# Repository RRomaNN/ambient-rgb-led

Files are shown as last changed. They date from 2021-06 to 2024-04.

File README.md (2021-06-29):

# Ambient backlight with addressable RGB strip [WIP]

This is a **prototype** of the LED backlight controller.

in short:

you can upload an image (ie pattern) from the computer to the device. The pattern will be read row by row by the controller and rows will be sequentially displayed on the addressable LED strip using the selected color schema with preselected speed and smooth color transitions between the rows.

Features:

- Supports up to 16 patterns, stored in 4x AT24C256 EEPROMs. You can interactively select one of them at a time.
- Supports up to 32 custom color schemas. You can create/edit/save them to EEPROM directly on the device using buttons, LCD and the short *preview* led strip.
- Supports different pattern playback speeds. From ~3 smooth transitions/second to 1 transition per 2 minutes. You can select the one you need.
- Measures amperage of the LED strip and displays it on the LCD in the operating mode. 
- TODO: Add feature, which allows limiting max current draw by LED strip to prevent damage of DC power supply / PCB.

- Load current - up to 10A.
- Distance between the controller and LED strip - up to 5 meters (the device contains repeater of the output digital signal)
- Protection from the minor static discharges over +5V, DOUT, GND lines (no TVS diodes though)

Schema:

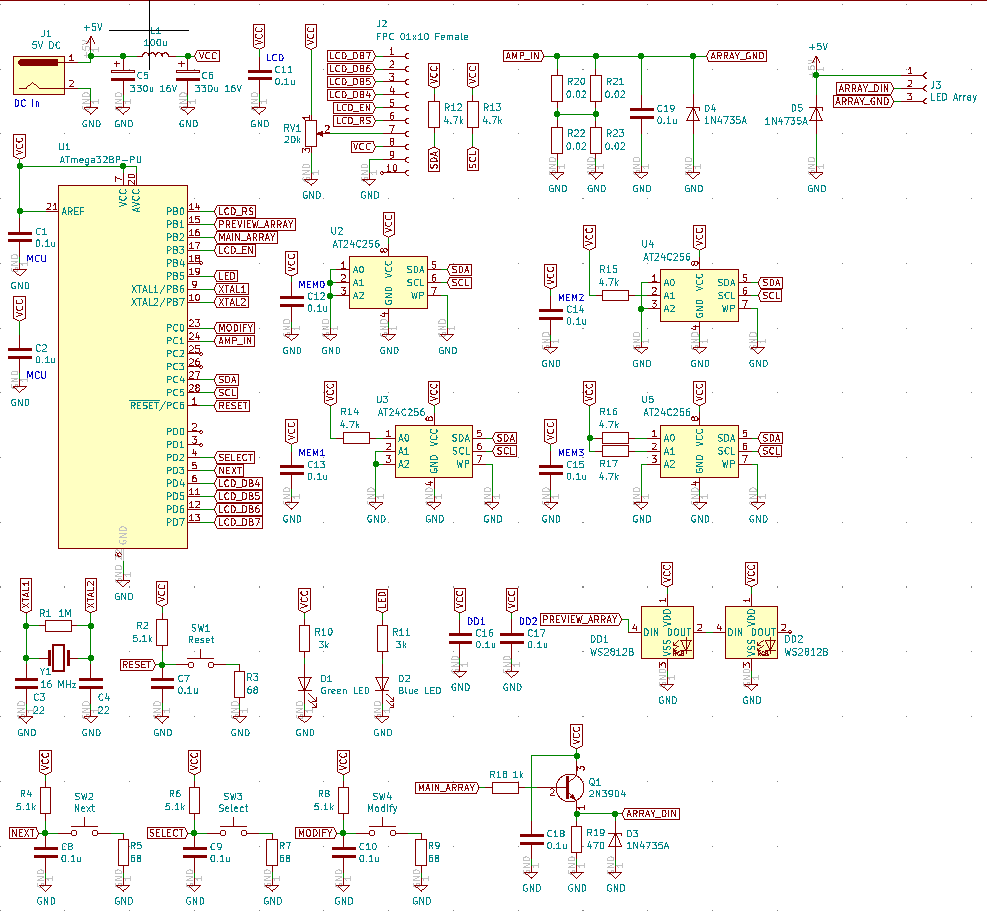
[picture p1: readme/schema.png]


PCB front view:

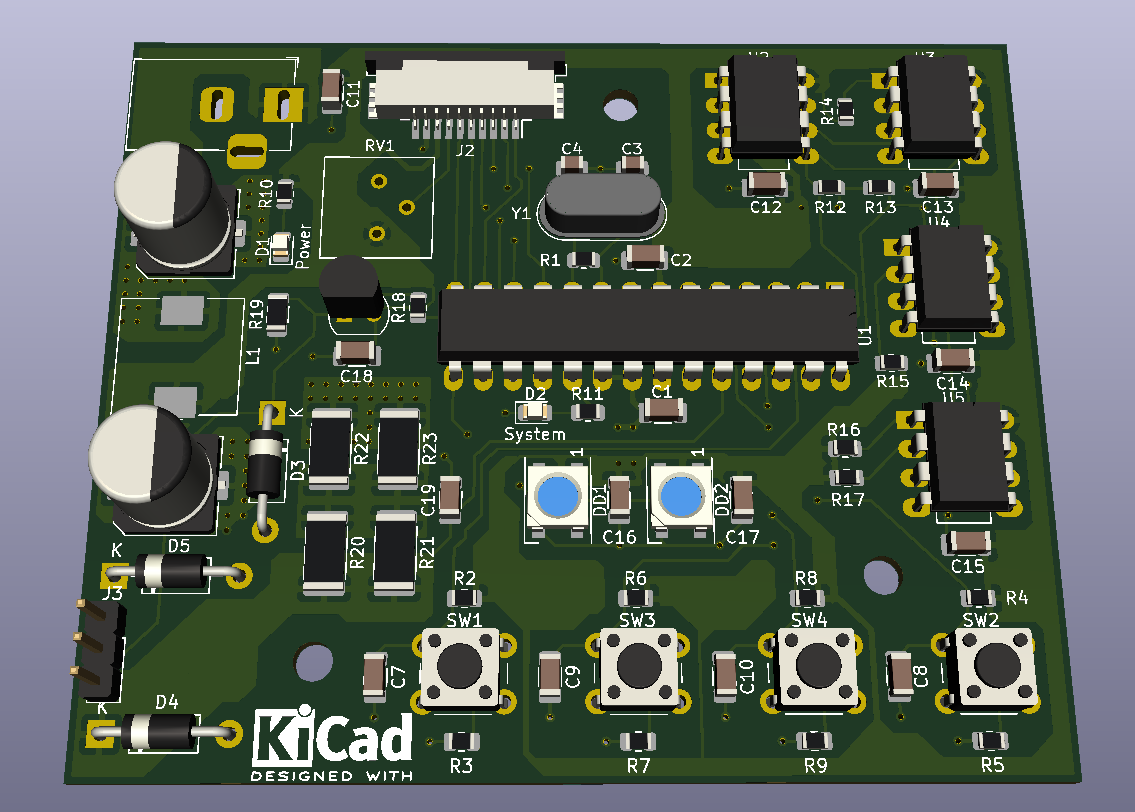
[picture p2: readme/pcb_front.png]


PCB back view:

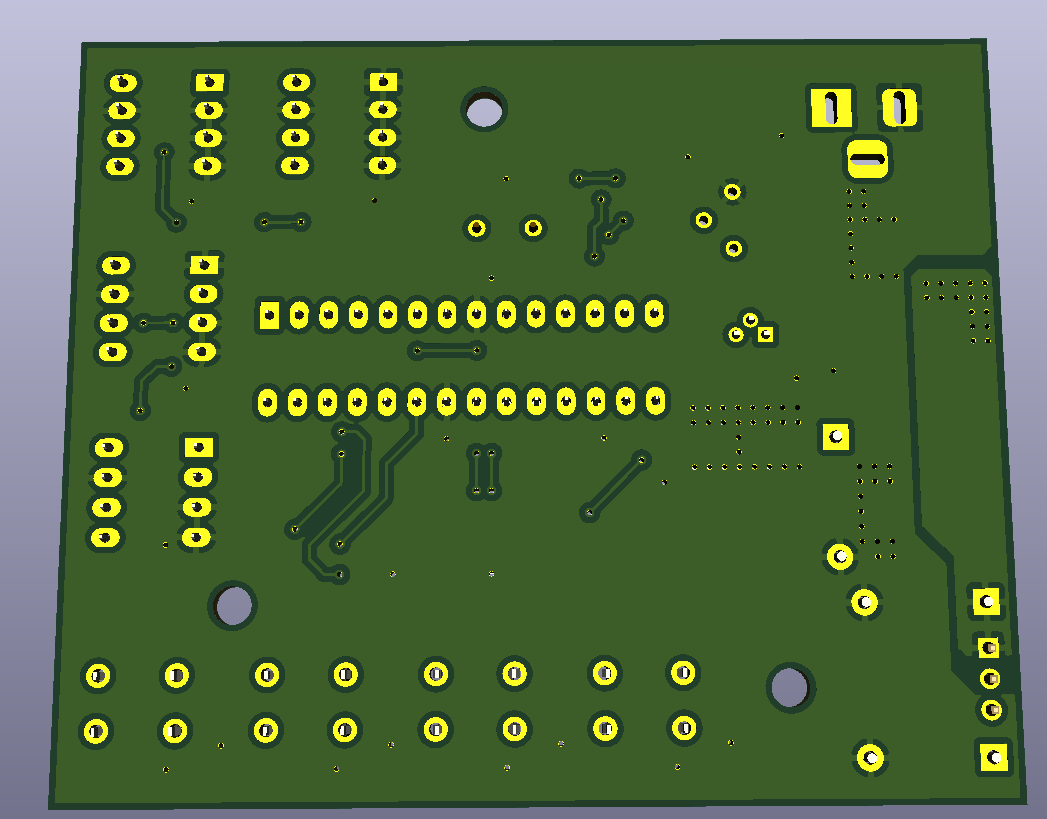
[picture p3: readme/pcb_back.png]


Firmware:

[controller.ino](https://github.com/RRomaNN/ambient-rgb-led/blob/main/controller_c/controller.ino)

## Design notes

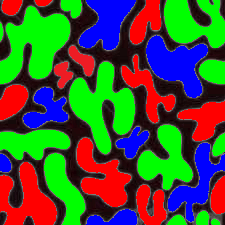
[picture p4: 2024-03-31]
image_converter_cs/BitConverter/4-color-image.bmp

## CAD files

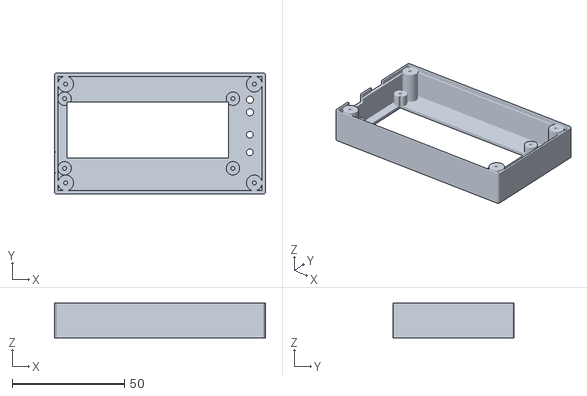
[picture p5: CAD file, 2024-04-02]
free-cad—cpy/front_v2.stl
94.0 x 54.0 x 15.6

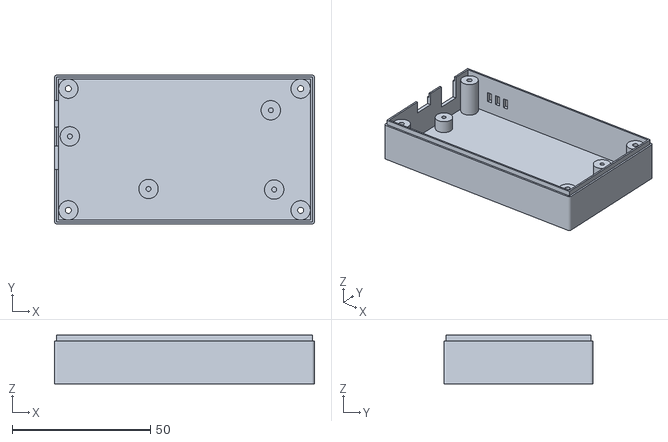
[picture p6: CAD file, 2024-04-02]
free-cad—cpy/back_v2.stl
94.0 x 54.0 x 17.5

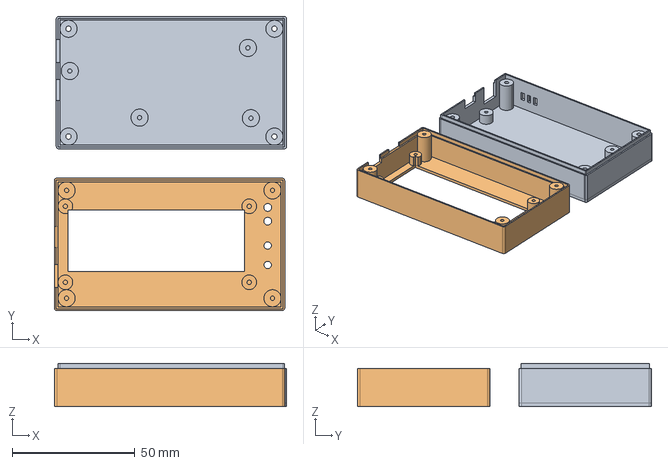
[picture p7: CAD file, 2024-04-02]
free-cad—cpy/case-bottom.FCStd
94.8 x 119.9 x 17.6 mm

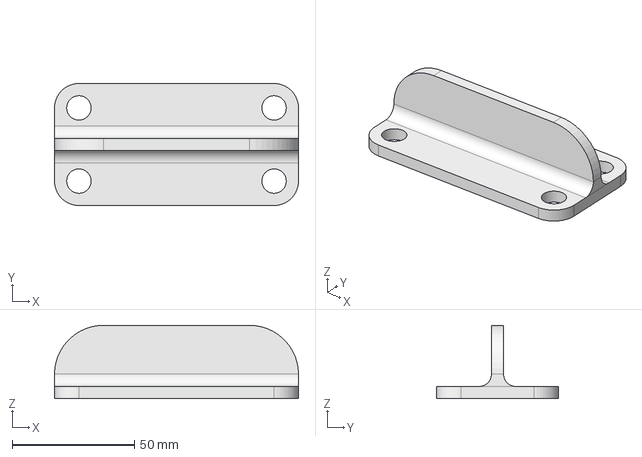
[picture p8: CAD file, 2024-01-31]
free-cad—cpy/test2.FCStd
100.0 x 50.0 x 30.0 mm

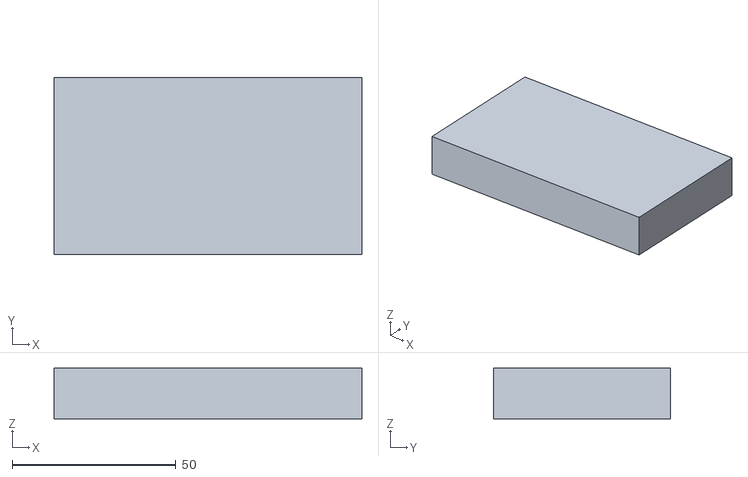
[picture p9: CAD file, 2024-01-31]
free-cad—cpy/case-bottom-Body001Pad009.stl
94.0 x 54.0 x 15.6

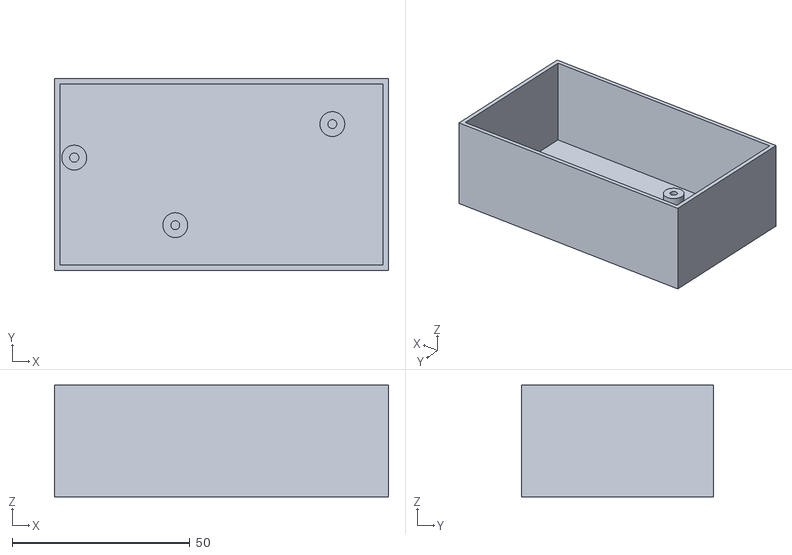
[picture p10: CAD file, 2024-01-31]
free-cad—cpy/case-bottom-BodyPocket002.stl
94.0 x 54.0 x 31.5

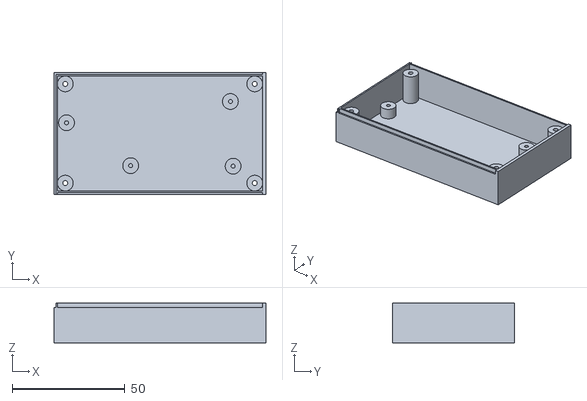
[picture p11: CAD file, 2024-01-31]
free-cad—cpy/case-bottom-BodyPocket010.stl
94.0 x 54.0 x 17.5

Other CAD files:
free-cad—cpy/test.FCStd
free-cad—cpy/test2-BodyFillet002.stl
free-cad—cpy/back.stl
free-cad—cpy/front.stl

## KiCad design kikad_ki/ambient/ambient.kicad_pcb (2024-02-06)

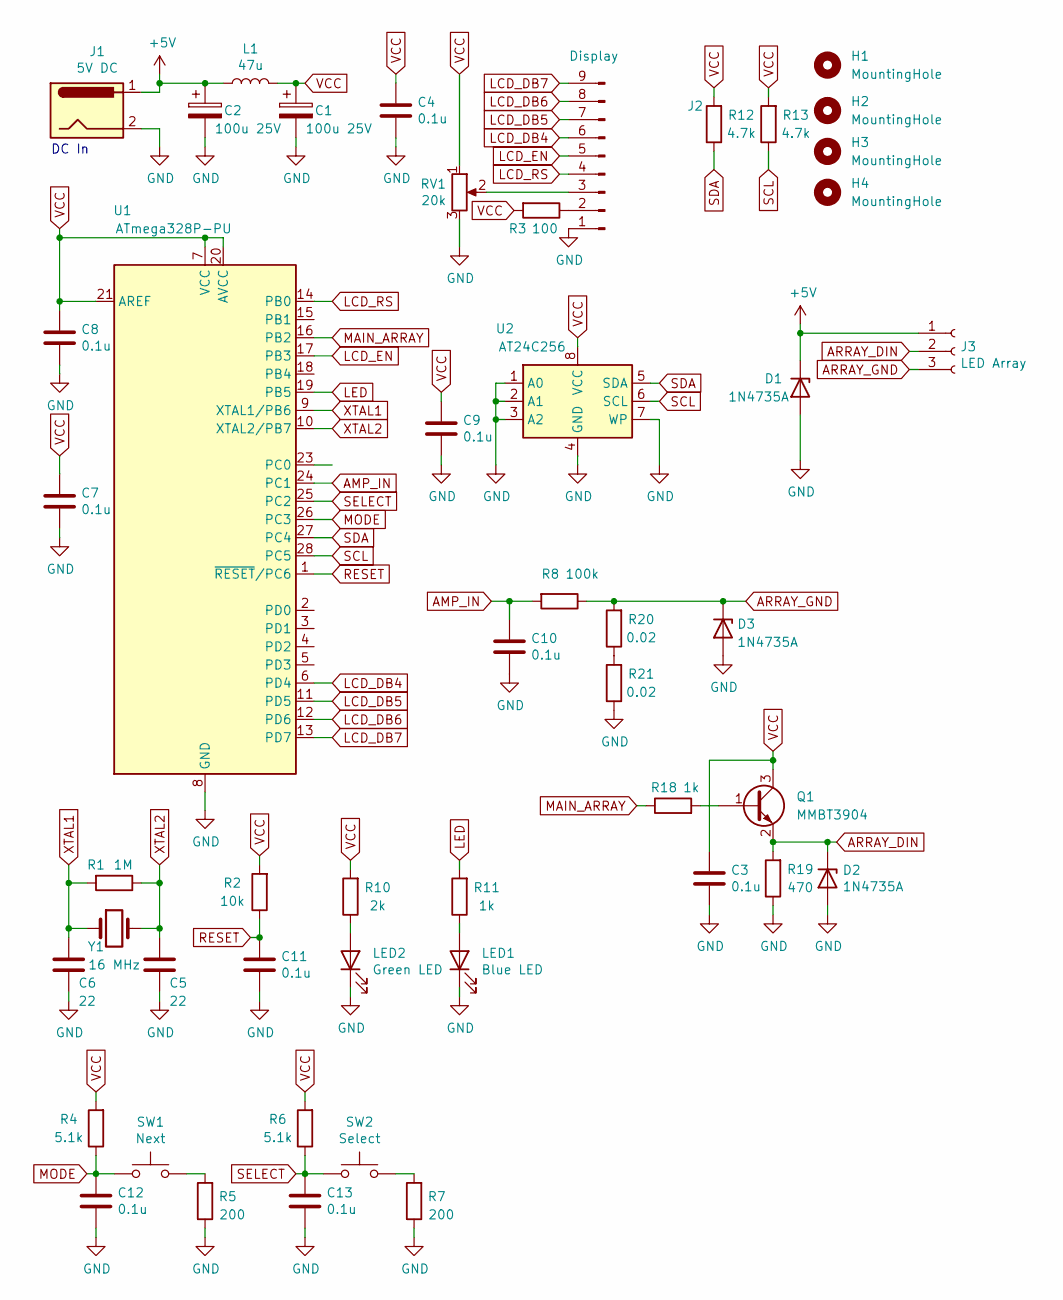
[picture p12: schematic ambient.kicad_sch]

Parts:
C1, C2: 100u 25V; CP_Elec_8x10
C3, C4, C7, C8, C9, C10, C11, C12, C13: 0.1u; C_0805_2012Metric
C5, C6: 22; C_0805_2012Metric
D1, D2, D3: 1N4735A; D_MiniMELF
H1, H2, H3, H4: MountingHole; MountingHole_3.2mm_M3_DIN965_Pad
J1: 5V DC; BarrelJack_Horizontal
J2: Display; PinHeader_1x09_P2.54mm_Vertical
J3: LED Array; PinHeader_1x03_P2.54mm_Vertical
L1: 47u; L_10.4x10.4_H4.8
LED1: Blue LED; LED_D3.0mm_Clear
LED2: Green LED; LED_D3.0mm_Clear
Q1: MMBT3904; SOT-23
R1: 1M; R_0805_2012Metric
R2: 10k; R_0805_2012Metric
R3: 100; R_1206_3216Metric
R4, R6: 5.1k; R_0805_2012Metric
R5, R7: 200; R_0805_2012Metric
R8: 100k; R_0805_2012Metric
R10: 2k; R_0805_2012Metric
R11, R18: 1k; R_0805_2012Metric
R12, R13: 4.7k; R_0805_2012Metric
R19: 470; R_1206_3216Metric
R20, R21: 0.02; R_2512_6332Metric
RV1: 20k; Potentiometer_Bourns_3386P_Vertical
SW1: Next; SW_PUSH_6mm
SW2: Select; SW_PUSH_6mm
U1: ATmega328P-PU; DIP-28_W7.62mm_LongPads
U2: AT24C256; DIP-8_W7.62mm_LongPads
Y1: 16 MHz; Crystal_HC49-4H_Vertical

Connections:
+5V: C2.1, D1.1 (K), J1.1, J3.1, L1.1
AMP_IN: C10.1, R8.2, U1.24 (PC1)
ARRAY_DIN: D2.1 (K), J3.2, Q1.2 (E), R19.2
ARRAY_GND: D3.1 (K), J3.3, R8.1, R20.2
GND: C1.2, C2.2, C3.2, C4.2, C5.2, C6.2, C7.2, C8.2, C9.2, C10.2, C11.2, C12.2, C13.2, D1.2 (A), D2.2 (A), D3.2 (A), J1.2, J2.1, LED1.1 (K), LED2.1 (K), R5.1, R7.1, R19.1, R21.1, RV1.3, U1.8 (GND), U1.22 (GND), U2.1 (A0), U2.2 (A1), U2.3 (A2), U2.4 (GND), U2.7 (WP)
LCD_DB4: J2.6, U1.6 (PD4)
LCD_DB5: J2.7, U1.11 (PD5)
LCD_DB6: J2.8, U1.12 (PD6)
LCD_DB7: J2.9, U1.13 (PD7)
LCD_EN: J2.5, U1.17 (PB3)
LCD_RS: J2.4, U1.14 (PB0)
LED: R11.2, U1.19 (PB5)
MAIN_ARRAY: R18.1, U1.16 (PB2)
MODE: C12.1, R4.1, SW1.1, U1.26 (PC3)
unnamed: J2.2, R3.1
unnamed: J2.3, RV1.2
unnamed: LED1.2 (A), R11.1
unnamed: LED2.2 (A), R10.1
unnamed: Q1.1 (B), R18.2
unnamed: R5.2, SW1.2
unnamed: R7.2, SW2.2
unnamed: R20.1, R21.2
RESET: C11.1, R2.1, U1.1 (~RESET/PC6)
SCL: R13.1, U1.28 (PC5), U2.6 (SCL)
SDA: R12.1, U1.27 (PC4), U2.5 (SDA)
SELECT: C13.1, R6.1, SW2.1, U1.25 (PC2)
VCC: C1.1, C3.1, C4.1, C7.1, C8.1, C9.1, L1.2, Q1.3 (C), R2.2, R3.2, R4.2, R6.2, R10.2, R12.2, R13.2, RV1.1, U1.7 (VCC), U1.20 (AVCC), U1.21 (AREF), U2.8 (VCC)
XTAL1: C6.1, R1.2, U1.9 (XTAL1/PB6), Y1.1
XTAL2: C5.1, R1.1, U1.10 (XTAL2/PB7), Y1.2

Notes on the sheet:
DC In

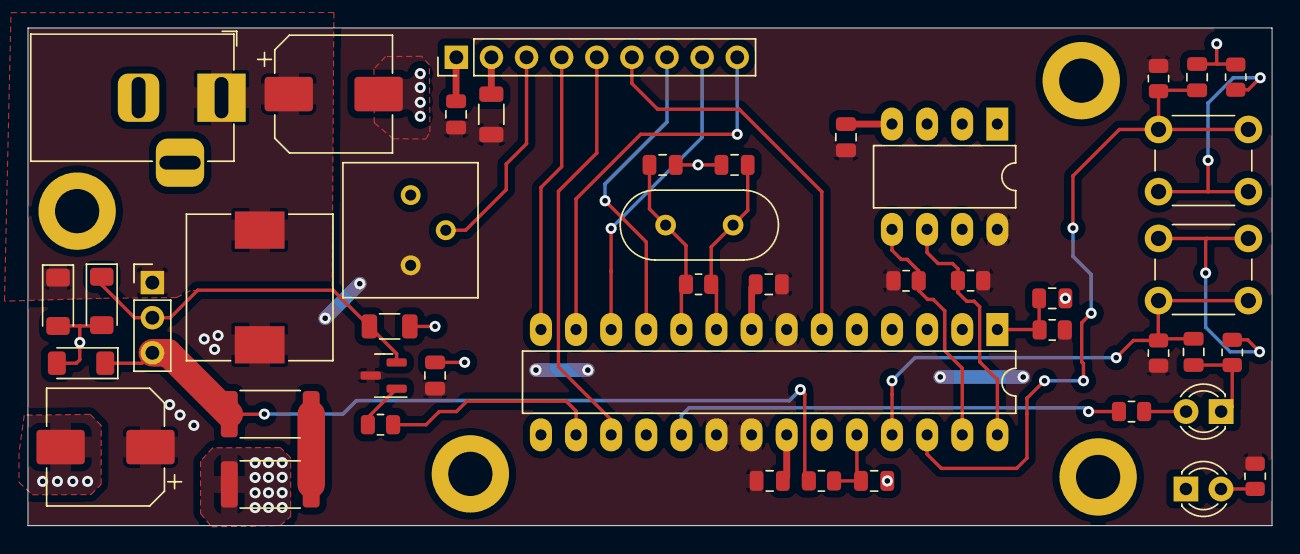
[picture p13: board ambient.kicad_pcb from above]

Board: 2 copper layers, 90.0 x 36.0 mm, 49 parts (0 on the bottom side), 29 nets.

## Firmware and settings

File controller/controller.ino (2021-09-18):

#include <Wire.h>
#include <LiquidCrystal.h>
#include <Adafruit_NeoPixel.h>

#define IRQ0 2
#define IRQ1 3

#define LCD_RS 8
#define LCD_EN 11
#define LCD_D4 4
#define LCD_D5 5
#define LCD_D6 6
#define LCD_D7 7

#define LED_PREVIEW_ARRAY_PIN 9
#define LED_MAIN_ARRAY_PIN 10

#define LED_PREVIEW_ARRAY_PIXEL_NUM 2
#define LED_MAIN_ARRAY_PIXEL_NUM 183

#define LED_ARRAY_BRIGHTNESS 240 // Not 255

#define EEPROM_BASE_ADDRESS 0x50

#define MAX_IMG_LEN 225
#define ARRAY_PATTERN_LEN 32

#define PATTERN_MAX_COUNT_PER_EEPROM 4
#define PATTERN_MAX_INDEX 3 // Pattern count - 1
#define MAX_PREDEFINED_COLORS 32

#define MODIFY_BUTTON_PIN A0
#define AMPERE_METER_PIN A1

#define AMPERE_METER_AVG_BUFF_SIZE 20
#define ADC_VOLT_TO_AMP_COEF 0.2443
#define MAX_LED_ARRAY_CURRENT 8.0

LiquidCrystal lcd(LCD_RS, LCD_EN, LCD_D4, LCD_D5, LCD_D6, LCD_D7);

Adafruit_NeoPixel preview_led_array(LED_PREVIEW_ARRAY_PIXEL_NUM, LED_PREVIEW_ARRAY_PIN, NEO_GRBW + NEO_KHZ800);
Adafruit_NeoPixel led_array(LED_MAIN_ARRAY_PIXEL_NUM, LED_MAIN_ARRAY_PIN, NEO_GRBW + NEO_KHZ800);

enum stateType {patternSelect, colorSelect, editMainRColor, editMainGColor, editMainBColor, editSecondaryRColor, editSecondaryGColor, editSecondaryBColor, speedSelect, validate, pause, resumeBack};
enum buttonType {selectButton, actionButton, modifyButton};

volatile enum stateType state = patternSelect; 

volatile int pattern_index = 0;
volatile int pattern_preview_line_offset = 0;

volatile char schema_name[12] = "N/A";

volatile char pattern_preview_line0[21];
volatile char pattern_preview_line1[21];
volatile char pattern_preview_line2[21];

volatile bool isSelectPressed = false;
volatile bool isActionPressed = false;

volatile byte main_red = 0xFF;
volatile byte main_green = 0xFF;
volatile byte main_blue = 0xFF;
volatile char main_color_hex[7];

volatile byte secondary_red = 0x00;
volatile byte secondary_green = 0x00;
volatile byte secondary_blue = 0x00;
volatile char secondary_color_hex[7];

volatile bool color_preview = false;
volatile int color_modify_reading_count = 0;
volatile int color_up_momentum = 0;
volatile int color_down_momentum = 0;
volatile byte color_index = 0;

volatile byte pattern_line_offset = 0;
volatile byte pattern_line_interval = 30;
volatile int pattern_count = 0;
volatile byte current_line_data[ARRAY_PATTERN_LEN];
volatile byte next_line_data[ARRAY_PATTERN_LEN];

volatile int currents[AMPERE_METER_AVG_BUFF_SIZE];
volatile byte currents_index = 0;

volatile byte ledArrayBrightness;

void setup() 
{  
  pinMode(LED_BUILTIN, OUTPUT);

  hello();
  
  cli();
 
  pinMode(IRQ0, INPUT);
  pinMode(IRQ1, INPUT);
 
  attachInterrupt(0, selectInterrupt, FALLING);    
  attachInterrupt(1, actionInterrupt, FALLING);  

  sei();

  Wire.begin();
  
  lcd.begin(20, 4);
  lcd.clear();

  preview_led_array.begin();
  preview_led_array.setBrightness(LED_ARRAY_BRIGHTNESS);

  ledArrayBrightness = LED_ARRAY_BRIGHTNESS;
  led_array.begin();
  led_array.setBrightness(ledArrayBrightness);

  readCurrentSchemaName(pattern_index);
  readCurrentPatternPreview(pattern_index, pattern_preview_line_offset);
  
  cancelPreviewColors();
  turnOffLedArray();

  readCurrentState();
  state = pause;
}

void hello()
{
  digitalWrite(LED_BUILTIN, HIGH);
  delay(100);
  digitalWrite(LED_BUILTIN, LOW);
  delay(100);
  digitalWrite(LED_BUILTIN, HIGH);
  delay(100);
  digitalWrite(LED_BUILTIN, LOW);
  delay(100);
  digitalWrite(LED_BUILTIN, HIGH);
  delay(100);
  digitalWrite(LED_BUILTIN, LOW);
}

void loop() 
{
  if(isSelectPressed)
  {
    transitState(selectButton);
    isSelectPressed = false;
  }

  if(isActionPressed)
  {
    transitState(actionButton);
    isActionPressed = false;
  }

  processModifyButton();
  if(color_modify_reading_count == 10)
  {
    color_modify_reading_count = 0;
    transitState(modifyButton);
  }

  render();

  if(state == patternSelect)
    preview();

  if((state == patternSelect || state == speedSelect || state == validate || state == pause || state == resumeBack) && color_preview)
  {
    color_preview = false;
    cancelPreviewColors();
  }    

  if(state == pause)
  {
    digitalWrite(LED_BUILTIN, HIGH);
    renderLedArray();
  }

  delay(100);
}

void renderLedArray()
{
  if(pattern_count == pattern_line_interval)
  {  
    pattern_count = 0;   
    
    //update pattern
    pattern_line_offset = pattern_line_offset == MAX_IMG_LEN - 1 ? 0 : pattern_line_offset + 1;

    byte eeprom_address = getEepromAddress(pattern_index);
    int patternBaseAddress = getAddressOffset(pattern_index);
    
    int patternAddress = patternBaseAddress + ARRAY_PATTERN_LEN * (1 + pattern_line_offset); //32 (256/8) * (225 + 1 for header) + header row;
    for(int i = 0; i < ARRAY_PATTERN_LEN; i++)
      current_line_data[i] = readEEPROM(eeprom_address, patternAddress + i);
      
    int nextPatternOffset = pattern_line_offset == MAX_IMG_LEN - 1 ? 0 : pattern_line_offset + 1;
    
    patternAddress = patternBaseAddress + ARRAY_PATTERN_LEN * (1 + nextPatternOffset);
    for(int i = 0; i < ARRAY_PATTERN_LEN; i++)
      next_line_data[i] = readEEPROM(eeprom_address, patternAddress + i);
  }
  else
    pattern_count++;

  setLedArrayColors();
  saveCurrentState();
}

void setLedArrayColors()
{
  float newFraction = (float)pattern_count / pattern_line_interval;
  float oldFraction = 1 - newFraction;
  
  for(byte i = 0; i < LED_MAIN_ARRAY_PIXEL_NUM; i++)
  {
    bool currentValue = current_line_data[i / 8] & (1 << i % 8);
    bool nextValue = next_line_data[i / 8] & (1 << i % 8);

    byte red, green, blue, white;
    if(currentValue && nextValue)
    {
      white = getWhite(main_red, main_green, main_blue);
      led_array.setPixelColor(i, led_array.Color(main_red - white, main_green - white, main_blue - white, white));  
      continue;
    }

    if(!currentValue && !nextValue)
    {
      white = getWhite(secondary_red, secondary_green, secondary_blue);
      led_array.setPixelColor(i, led_array.Color(secondary_red - white, secondary_green - white, secondary_blue - white, white));  
      continue;
    }

    if(currentValue && !nextValue)
    {
      red = main_red * oldFraction + secondary_red * newFraction;
      green = main_green * oldFraction + secondary_green * newFraction;
      blue = main_blue * oldFraction + secondary_blue * newFraction; 
    }
    else
    {
      red = main_red * newFraction + secondary_red * oldFraction;
      green = main_green * newFraction + secondary_green * oldFraction;
      blue = main_blue * newFraction + secondary_blue * oldFraction; 
    }
    white = getWhite(red, green, blue);
    led_array.setPixelColor(i, led_array.Color(red - white, green - white, blue - white, white)); 
  }
  led_array.show();
}

byte getWhite(byte red, byte green, byte blue)
{
  byte rb = red < green ? red : green;
  return rb < blue ? rb : blue;
}


void processModifyButton()
{
  int modify_button_reading = analogRead(MODIFY_BUTTON_PIN);
  if(modify_button_reading < 256)
    color_modify_reading_count++;
  else
    color_modify_reading_count = 0;
}

void preview()
{
  pattern_preview_line_offset = pattern_preview_line_offset == MAX_IMG_LEN - 1 ? 0 : pattern_preview_line_offset + 1;
  readCurrentPatternPreview(pattern_index, pattern_preview_line_offset);
}

void selectInterrupt()
{
  if(!isSelectPressed)
    isSelectPressed = true;
}

void actionInterrupt()
{
  if(!isActionPressed)
    isActionPressed = true;
}

void transitState(enum buttonType button)
{
  switch(state)
  {
    case patternSelect:
      switch(button)
      {
        case selectButton:
          pattern_index = pattern_index == PATTERN_MAX_INDEX ? 0 : pattern_index + 1;
          readCurrentSchemaName(pattern_index);    
          readCurrentPatternPreview(pattern_index, pattern_preview_line_offset);
          break;
        case actionButton:
          state = colorSelect;
          readColors();
          break;
      }
      break;
    case colorSelect:
      switch(button)
      {
        case selectButton:
          color_index = color_index == MAX_PREDEFINED_COLORS - 1 ? 0 : color_index + 1;
          readColors();
          break;
        case actionButton:
          state = speedSelect;
          break;
        case modifyButton:
          state = editMainRColor;
          break;
      }
      break;
    case editMainRColor:
      switch(button)
      {
        case selectButton:
          main_red = colorDown(main_red);
          break;
        case actionButton:
          main_red = colorUp(main_red);
          break;
        case modifyButton:
          state = editMainGColor;
          break;
      }
      break;
    case editMainGColor:
      switch(button)
      {
        case selectButton:
          main_green = colorDown(main_green);
          break;
        case actionButton:
          main_green = colorUp(main_green);
          break;
        case modifyButton:
          state = editMainBColor;
          break;
      }
      break;
    case editMainBColor:
      switch(button)
      {
        case selectButton:
          main_blue = colorDown(main_blue);
          break;
        case actionButton:
          main_blue = colorUp(main_blue);
          break;
        case modifyButton:
          state = editSecondaryRColor;
          break;
      }
      break;
    case editSecondaryRColor:
      switch(button)
      {
        case selectButton:
          secondary_red = colorDown(secondary_red);
          break;
        case actionButton:
          secondary_red = colorUp(secondary_red);
          break;
        case modifyButton:
          state = editSecondaryGColor;
          break;
      }
      break;
    case editSecondaryGColor:
      switch(button)
      {
        case selectButton:
          secondary_green = colorDown(secondary_green);
          break;
        case actionButton:
          secondary_green = colorUp(secondary_green);
          break;
        case modifyButton:
          state = editSecondaryBColor;
          break;
      }
      break;
    case editSecondaryBColor:
      switch(button)
      {
        case selectButton:
          secondary_blue = colorDown(secondary_blue);
          break;
        case actionButton:
          secondary_blue = colorUp(secondary_blue);
          break;
        case modifyButton:
          state = colorSelect;
          writeColors();
          break;
      }
      break;
    case speedSelect:
      switch(button)
      {
        case selectButton:
          modifyPatternLineInterval();
          break;
        case actionButton:
          state = validate;
          break;
      }
      break;
    case validate:
      switch(button)
      {
        case selectButton:
          pattern_count = pattern_line_interval;
          pattern_line_offset = MAX_IMG_LEN - 1;
          state = pause;
          break;
        case actionButton:
          state = patternSelect;
          break;
      }
      break;
    case pause:
      switch(button)
      {
        case selectButton:
          state = resumeBack;
          break;
        case actionButton:
          turnOffLedArray();
          digitalWrite(LED_BUILTIN, LOW);
          state = patternSelect;
          break;
      }
      break;
    case resumeBack:
      switch(button)
      {
        case selectButton:
          state = pause;
          break;
        case actionButton:
          state = patternSelect;
          break;
      }
      break;
  }
}

void modifyPatternLineInterval()
{
  if(pattern_line_interval > 5 && pattern_line_interval <= 30) 
    pattern_line_interval -= 5;
  else if(pattern_line_interval > 1 && pattern_line_interval <= 5)
    pattern_line_interval -= 2;
  else if(pattern_line_interval == 1)
    pattern_line_interval = 240;
  else
    pattern_line_interval -= 30;
}

byte colorUp(byte color)
{
  color_up_momentum++;
  color_down_momentum = 0;
  return color = color == 0xFF ? 0x00 : color + color_up_momentum;
}

byte colorDown(byte color)
{
  color_down_momentum++;
  color_up_momentum = 0;
  return color = color == 0x00 ? 0xFF : color - color_down_momentum;
}

void render() 
{
  lcd.setCursor(0, 0);
  
  switch(state)
  {
    case patternSelect:
      printPatternPreview();
      lcd.print((char*)schema_name);
      printIterationNumber();
      lcd.print(" Next");
      break;
    case colorSelect:
      setColorStrings();
      previewColors();
      lcd.print("Choose colors   [");
      printNumber(color_index);
      lcd.print("]");
      displayColorStrings();
      renderChoice("Select  Modify  Next");
      break;
    case editMainRColor:
      setColorStrings();
      previewColors();
      lcd.print("Set main red        ");
      displayColorStrings();
      renderChoice("-    Main green    +");
      break;
    case editMainGColor:
      setColorStrings();
      previewColors();
      lcd.print("Set main green      ");
      displayColorStrings();
      renderChoice("-    Main blue     +");    
      break;
    case editMainBColor:
      setColorStrings();
      previewColors();
      lcd.print("Set main blue       ");
      displayColorStrings();
      renderChoice("-  Secondary red   +");    
      break;
    case editSecondaryRColor:
      setColorStrings();
      previewColors();
      lcd.print("Set secondary red   ");
      displayColorStrings();
      renderChoice("- Secondary green  +");
      break;
    case editSecondaryGColor:
      setColorStrings();
      previewColors();
      lcd.print("Set secondary green ");
      displayColorStrings();
      renderChoice("-  Secondary blue  +");    
      break;
    case editSecondaryBColor:
      setColorStrings();
      previewColors();
      lcd.print("Set secondary blue  ");
      displayColorStrings();
      renderChoice("-      Apply       +");    
      break;
    case speedSelect:
      lcd.print("Set iteration count ");
      displaySpeedStrings();
      renderChoice("Select          Next");
      break;
    case validate:
      lcd.print("Pattern: ");
      lcd.print((char*)schema_name);
      displayColorStrings();
      renderChoice("Apply@");
      print3dNumberFwd(pattern_line_interval);
      lcd.print("     Cancel");
      break;
    case pause:
      lcd.print("Pattern: ");
      lcd.print((char*)schema_name);
      lcd.setCursor(0, 1);
      lcd.print("Line: ");
      print3dNumberFwd(pattern_line_offset);
      lcd.print("           ");
      printCurrentMeterValue();
      renderChoice("Pause            Off");
      break;
    case resumeBack:
      lcd.print("Pattern: ");
      lcd.print((char*)schema_name);
      lcd.setCursor(0, 1);
      lcd.print("Iteration:       ");
      print3dNumberFwd(pattern_line_offset);
      printCurrentMeterValue();
      renderChoice("Resume           Off");
      break;
  } 
}

void displaySpeedStrings()
{
  lcd.setCursor(0, 1);
  lcd.print("Interval:        ");
  print3dNumber(pattern_line_interval);
  lcd.setCursor(0, 2);
  lcd.print("                    ");
}


void printPatternPreview()
{
  lcd.print((char*)pattern_preview_line0);
  lcd.setCursor(0, 1);
  lcd.print((char*)pattern_preview_line1);
  lcd.setCursor(0, 2);
  lcd.print((char*)pattern_preview_line2);
  lcd.setCursor(0, 3);
}

void printCurrentMeterValue()
{
  currents[currents_index] = analogRead(AMPERE_METER_PIN);
  currents_index = currents_index == AMPERE_METER_AVG_BUFF_SIZE - 1 ? 0 : currents_index + 1;
  int sum = 0;
  for(int i = 0; i < AMPERE_METER_AVG_BUFF_SIZE; i++)
    sum += currents[i];          
  float current = sum * ADC_VOLT_TO_AMP_COEF / AMPERE_METER_AVG_BUFF_SIZE;  
  lcd.setCursor(0, 2);
  lcd.print("LED current: ");
  if(ledArrayBrightness)
  {
    lcd.print(current);
    lcd.print(" A ");
  }
  else
    lcd.print("HIGH!!!");    

  checkCurrent(current);
}

void checkCurrent(float current)
{
  if(current > MAX_LED_ARRAY_CURRENT && ledArrayBrightness > 0)
  {
    ledArrayBrightness = 0;
    led_array.setBrightness(ledArrayBrightness);
  }
}

void printNumber(byte number)
{
  if(number < 10)
    lcd.print(" ");
  lcd.print(number);
}

void print3dNumber(byte number)
{
  if(number < 10)
    lcd.print(" ");
  if(number < 100)
    lcd.print(" ");
  lcd.print(number);
}

void print3dNumberFwd(byte number)
{
  lcd.print(number);
  if(number < 10)
    lcd.print(" ");
  if(number < 100)
    lcd.print(" ");
}

void displayColorStrings()
{
  lcd.setCursor(0, 1);
  lcd.print("RGB Main      ");
  lcd.print((char*)main_color_hex);
  lcd.setCursor(0, 2);
  lcd.print("RGB Secondary ");
  lcd.print((char*)secondary_color_hex);
}

void previewColors()
{
  byte white = getWhite(main_red, main_green, main_blue);
  preview_led_array.setPixelColor(0, preview_led_array.Color(main_red - white, main_green - white, main_blue - white, white));
  white = getWhite(secondary_red, secondary_green, secondary_blue);
  preview_led_array.setPixelColor(1, preview_led_array.Color(secondary_red - white, secondary_green - white, secondary_blue - white, white));
  preview_led_array.show();
  color_preview = true;
}

void cancelPreviewColors()
{
  preview_led_array.setPixelColor(0, preview_led_array.Color(0x00, 0x00, 0x00, 0x00));
  preview_led_array.setPixelColor(1, preview_led_array.Color(0x00, 0x00, 0x00, 0x00));
  preview_led_array.show();
}

void turnOffLedArray()
{
  for(byte i = 0; i < LED_MAIN_ARRAY_PIXEL_NUM; i++)
    led_array.setPixelColor(i, led_array.Color(0x00, 0x00, 0x00, 0x00));
  led_array.show();
}

void readColors()
{
  int baseAddress = getColorSetBaseAddress();
  
  main_red = readEEPROM(EEPROM_BASE_ADDRESS, baseAddress++);
  main_green = readEEPROM(EEPROM_BASE_ADDRESS, baseAddress++);
  main_blue = readEEPROM(EEPROM_BASE_ADDRESS, baseAddress++);
  secondary_red = readEEPROM(EEPROM_BASE_ADDRESS, baseAddress++);
  secondary_green = readEEPROM(EEPROM_BASE_ADDRESS, baseAddress++);
  secondary_blue = readEEPROM(EEPROM_BASE_ADDRESS, baseAddress++);
}

void writeColors()
{
  int baseAddress = getColorSetBaseAddress();
  
  writeEEPROM(EEPROM_BASE_ADDRESS, baseAddress++, main_red);
  writeEEPROM(EEPROM_BASE_ADDRESS, baseAddress++, main_green);
  writeEEPROM(EEPROM_BASE_ADDRESS, baseAddress++, main_blue);
  writeEEPROM(EEPROM_BASE_ADDRESS, baseAddress++, secondary_red);
  writeEEPROM(EEPROM_BASE_ADDRESS, baseAddress++, secondary_green);
  writeEEPROM(EEPROM_BASE_ADDRESS, baseAddress++, secondary_blue);
}

int getColorSetBaseAddress()
{
  return PATTERN_MAX_COUNT_PER_EEPROM * ARRAY_PATTERN_LEN * (MAX_IMG_LEN + 1) + 6 * color_index; // 4 x schema + RGBRGB x index
}

void readCurrentState()
{
  int baseAddress = getMemoBaseAddress();

  pattern_index = readEEPROM(EEPROM_BASE_ADDRESS, baseAddress++);
  color_index = readEEPROM(EEPROM_BASE_ADDRESS, baseAddress++);
  readColors();
  pattern_count = pattern_line_interval = readEEPROM(EEPROM_BASE_ADDRESS, baseAddress++);
}

void saveCurrentState()
{
  int baseAddress = getMemoBaseAddress();

  writeEEPROM(EEPROM_BASE_ADDRESS, baseAddress++, pattern_index);
  writeEEPROM(EEPROM_BASE_ADDRESS, baseAddress++, color_index);
  writeEEPROM(EEPROM_BASE_ADDRESS, baseAddress++, pattern_line_interval);
}

int getMemoBaseAddress()
{
  return PATTERN_MAX_COUNT_PER_EEPROM * ARRAY_PATTERN_LEN * (MAX_IMG_LEN + 1) + 6 * MAX_PREDEFINED_COLORS; // 4 x schema + RGBRGB x color set count
}

void printIterationNumber()
{
  if(pattern_preview_line_offset < 10) 
  {
    lcd.print("   ");
    lcd.print(pattern_preview_line_offset);
  } 
  else if(pattern_preview_line_offset < 100)
  {
    lcd.print("  ");
    lcd.print(pattern_preview_line_offset);
  }
  else
  {
    lcd.print(" ");
    lcd.print(pattern_preview_line_offset);
  }
}

void setColorStrings()
{  
  byte color_main_bytes[3] = {main_red, main_green, main_blue};
  byte color_secondary_bytes[3] = {secondary_red, secondary_green, secondary_blue};
  arrayToString(color_main_bytes, 3, main_color_hex);
  arrayToString(color_secondary_bytes, 3, secondary_color_hex);
}

void arrayToString(byte array[], unsigned int len, char buffer[])
{
  for (unsigned int i = 0; i < len; i++)
  {
    byte nib1 = (array[i] >> 4) & 0x0F;
    byte nib2 = (array[i] >> 0) & 0x0F;
    buffer[i*2+0] = nib1  < 0xA ? '0' + nib1  : 'A' + nib1  - 0xA;
    buffer[i*2+1] = nib2  < 0xA ? '0' + nib2  : 'A' + nib2  - 0xA;
  }
  buffer[len*2] = '\0';
}

void renderChoice(char* bottomLine)
{
  lcd.setCursor(0, 3);
  lcd.print(bottomLine);
}

void readCurrentSchemaName(int index)
{
  byte eeprom_address = getEepromAddress(index);
  int nameBaseAddress = getAddressOffset(index); 
  for(int i = 0; i < 11; i++)
    schema_name[i] = (char)readEEPROM(eeprom_address, nameBaseAddress + i);
  schema_name[11] = '\0';
}

void readCurrentPatternPreview(int index, int lineOffset)
{
  byte eeprom_address = getEepromAddress(index);
  int patternBaseAddress = getAddressOffset(index);
  int patternAddress = patternBaseAddress + ARRAY_PATTERN_LEN * (1 + lineOffset); //32 (256/8) * (225 + 1 for header) + header row;
  for(int i = 0; i < 20; i++)
    pattern_preview_line0[i] = readPatternLineChar(eeprom_address, patternAddress, i);
  pattern_preview_line0[20] = '\0';
  patternAddress = patternBaseAddress + ARRAY_PATTERN_LEN * (1 + (lineOffset + 1) % MAX_IMG_LEN);
  for(int i = 0; i < 20; i++)
    pattern_preview_line1[i] = readPatternLineChar(eeprom_address, patternAddress, i);
  pattern_preview_line1[20] = '\0';
  patternAddress = patternBaseAddress + ARRAY_PATTERN_LEN * (1 + (lineOffset + 2) % MAX_IMG_LEN);
  for(int i = 0; i < 20; i++)
    pattern_preview_line2[i] = readPatternLineChar(eeprom_address, patternAddress, i);
  pattern_preview_line2[20] = '\0';
}

byte readPatternLineChar(byte eeprom_address, int patternBaseAddress, int bitIndex)
{
  return (readEEPROM(eeprom_address, (patternBaseAddress + bitIndex/8)) & (1 << bitIndex % 8)) ? char(255) : ' ';
}
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

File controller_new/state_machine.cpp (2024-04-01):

#include "state_machine.hpp"

StateMachine::StateMachine(uint8_t selected_pattern, uint8_t selected_color2, uint8_t selected_color4, uint8_t selected_speed, uint8_t led_count, bool preview_colors, bool is_rgbw_strip)
{
  current_mode = BackgroundMode;

  this->selected_pattern = selected_pattern;
  this->selected_color2 = selected_color2;
  this->selected_color4 = selected_color4;
  this->selected_speed = selected_speed;
  this->led_count = led_count;
  this->preview_colors = preview_colors;
  this->is_rgbw_strip = is_rgbw_strip;
}

void StateMachine::DecreaseColor(uint8_t color_setting_phase, uint32_t* color_x)
{
  uint8_t color_offset = color_setting_phase * 8;
  uint32_t color = (*color_x >> color_offset) & (uint32_t)0x000000FF;
  color = color == 0 ? 0xFF : color - 1;
  uint32_t new_part = color << color_offset;
  uint32_t old_part = *color_x & (~((uint32_t)0x000000FF << color_offset));
  *color_x = (new_part + old_part) & (uint32_t)0x00FFFFFF;
}

void StateMachine::IncreaseColor(uint8_t color_setting_phase, uint32_t* color_x)
{
  uint8_t color_offset = color_setting_phase * 8;
  uint32_t color = (*color_x >> color_offset) & (uint32_t)0x000000FF;
  color = color == 0xFF ? 0 : color + 1;
  uint32_t new_part = color << color_offset;
  uint32_t old_part = *color_x & (~((uint32_t)0x000000FF << color_offset));
  *color_x = (new_part + old_part) & (uint32_t)0x00FFFFFF;
}

void StateMachine::IncreaseColorStrongly(uint8_t color_setting_phase, uint32_t* color_x)
{
  uint8_t color_offset = color_setting_phase * 8;
  uint32_t color = (*color_x >> color_offset) & (uint32_t)0x000000FF;
  color = (color + StrongColorIncreaseDelta) % (uint32_t)0x00000100;
  uint32_t new_part = color << color_offset;
  uint32_t old_part = *color_x & (~((uint32_t)0x000000FF << color_offset));
  *color_x = (new_part + old_part) & (uint32_t)0x00FFFFFF;
}

void StateMachine::ProcessColorSettingMode(ActionType action, uint32_t* color_a, uint32_t* color_b, ModeType next_mode)
{
  switch(action)
  {
    case Select: // v
      if (color_setting_phase < 3) //first color
        DecreaseColor(color_setting_phase, color_a);
      else
        DecreaseColor(color_setting_phase - 3, color_b);
      break;
    case SelectLong:
      if (color_setting_phase < 3) //first color
        IncreaseColorStrongly(color_setting_phase, color_a);
      else
        IncreaseColorStrongly(color_setting_phase - 3, color_b);
      break;
    case Mode: // ^
      if (color_setting_phase < 3) //first color
        IncreaseColor(color_setting_phase, color_a);
      else
        IncreaseColor(color_setting_phase - 3, color_b);
      break;
    case ModeLong:
      if (color_setting_phase < ColorSetPhaseCount - 1)
        ++color_setting_phase;
      else
      {
        color_setting_phase = 0;
        current_mode = next_mode;
      }
      break;
  }
}

void StateMachine::TransitState(ActionType action)
{
  switch(current_mode)
  {
    case BackgroundMode:
      switch(action)
      {
        case SelectLong:
          current_mode = LedCountSelectMode;
          break;
        case Select:
          current_mode = PreviewColorMode;
          break;
        case Mode:
        case ModeLong:
          current_mode = PatternSelectMode;
          break;
      }
      break;
    case LedCountSelectMode:
      switch(action)
        {
          case Select: // v
            led_count = (led_count == 0) ? MaxLedCount : led_count - 1;
            break;
          case SelectLong: // ^^
            led_count = (led_count + FastLedCountChangeDelta) % (MaxLedCount + 1);
            break;
          case Mode: // ^
            led_count = (led_count == MaxLedCount) ? 0 : led_count + 1;
            break;
          case ModeLong:
            current_mode = SelectStripTypeMode;
            break;
        }
      break;
    case PatternSelectMode:
      switch(action)
      {
        case Select:
        case SelectLong:
          selected_pattern = (selected_pattern == PatternCount - 1) ? 0 : selected_pattern + 1;
          break;
        case Mode:
        case ModeLong:
          current_mode = ColorSelectMode;
          break;
      }
      break;
    case ColorSelectMode:
      switch(action)
      {
        case Mode:        
          if (selected_pattern == 0)               
            selected_color2 = (selected_color2 == ColorCount - 1) ? 0 : selected_color2 + 1;
          else
            selected_color4 = (selected_color4 == ColorCount - 1) ? 0 : selected_color4 + 1;
          break;
        case Select:
          if (selected_pattern == 0)      
            selected_color2 = (selected_color2 == 0) ? ColorCount - 1 : selected_color2 - 1;
          else
            selected_color4 = (selected_color4 == 0) ? ColorCount - 1 : selected_color4 - 1;
          break;
        case ModeLong:
          current_mode = SpeedSelectMode;
          break;
        case SelectLong:       
          color_setting_phase = 0;
          if (selected_pattern == 0)   
            current_mode = Color2SettingMode;
          else
            current_mode = Color4Setting0Mode;
          break;
      }
      break;
    case Color2SettingMode:
      ProcessColorSettingMode(action, &color0, &color1, SpeedSelectMode);
      break;
    case Color4Setting0Mode:
      ProcessColorSettingMode(action, &color0, &color1, Color4Setting1Mode);
      break;
    case Color4Setting1Mode:
      ProcessColorSettingMode(action, &color2, &color3, SpeedSelectMode);
      break;
    case SpeedSelectMode:
      switch(action)
        {
          case Select: // v
            selected_speed = (selected_speed == 0) ? SlowestChangeSpeed : selected_speed - 1;
            break;
          case SelectLong: // ^^
            selected_speed = (selected_speed + FastSpeedChangeDelta) % (SlowestChangeSpeed + 1);
            break;
          case Mode: // ^
            selected_speed = (selected_speed == SlowestChangeSpeed) ? 0 : selected_speed + 1;
            break;
          case ModeLong:
            current_mode = BackgroundMode;
            break;
        }
      break;
    case PreviewColorMode:
      switch(action)
      {
        case Select:
        case Mode:
        case SelectLong:
          preview_colors = !preview_colors;
          break;
        case ModeLong:
          current_mode = BackgroundMode;
          break;
      }
      break;
    case SelectStripTypeMode:
      switch(action)
      {
        case Select:
        case Mode:
        case SelectLong:
          is_rgbw_strip = !is_rgbw_strip;
          break;
        case ModeLong:
          current_mode = RestartNeededMode;
          break;
      }
      break;
    case RestartNeededMode:
      switch(action)
      {
        case Select:
        case Mode:
        case SelectLong:
        case ModeLong:
          current_mode = RestartIsReallyNeededMode;
          break;
      }
      break;
  }
}

StateMachine::ModeType StateMachine::GetCurrentMode()
{
  return current_mode;
}
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

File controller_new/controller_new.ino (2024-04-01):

#include "button_module.hpp"
#include "init_helper.hpp"
#include "neopixel.hpp"
#include "lcd.hpp"
#include "menu.hpp"
#include "command_processor.hpp"
#include "rendering_engine.hpp"

LPLedIndicator led_indicatior;
LPStateMachine state_machine;
LPButtonModule button_module;
LPEeprom eeprom;
LPPowerController pwr_controller;
LPNeoPixel neopixel;
LPLcd lcd;
LPMenu menu;
LPCommandProcessor command_processor;
LPRendringEngine rendering_engine;

bool global_lock;
uint8_t menu_counter;
bool need_to_refresh_menu;

void setup() 
{
  global_lock = false;
  menu_counter = 0;
  need_to_refresh_menu = true;

  InitHelper::InitGpioPins();
  InitHelper::InitI2C();

  led_indicatior = new LedIndicator();
  eeprom = new Eeprom();
  lcd = new Lcd();
  button_module = new ButtonModule();
  pwr_controller = new PowerController(led_indicatior, &global_lock, neopixel, lcd);

  pwr_controller->AuditPowerStatusAndAct();

  if (eeprom->Ping())
  {
    lcd->PrintMemTestError();
    led_indicatior->Blink(3, LONG_SIGNAL_MS, LONG_SIGNAL_MS);
    global_lock = true;
  }

  uint8_t selected_pattern, selected_color2, selected_color4, strip_led_count, selected_speed;
  bool preview_colors, is_rgbw_strip;
  eeprom->ReadSavedSettings(&selected_pattern, &selected_color2, &selected_color4, &selected_speed, &strip_led_count, &preview_colors, &is_rgbw_strip);

  state_machine = new StateMachine(selected_pattern, selected_color2, selected_color4, selected_speed, strip_led_count, preview_colors, is_rgbw_strip);
  uint32_t color_a, color_b, color_c = 0x0, color_d = 0x0;
  if (selected_pattern == 0)
    eeprom->ReadColor2Schema(selected_color2, &color_a, &color_b);
  else 
    eeprom->ReadColor4Schema(selected_color4, &color_a, &color_b, &color_c, &color_d);
  state_machine->SetSelectedColors(color_a, color_b, color_c, color_d);

  neopixel = new NeoPixel(strip_led_count, is_rgbw_strip);
  rendering_engine = new RendringEngine(state_machine, eeprom, neopixel);
  command_processor = new CommandProcessor(state_machine, eeprom, rendering_engine, led_indicatior);
  menu = new Menu(lcd, state_machine);
      
  led_indicatior->Blink(3, SHORT_SIGNAL_MS, SHORT_SIGNAL_MS);
}

void loop() 
{
  if (global_lock)
  {
    delay(1000);
    return;
  }

  command_processor->ProcessStateChanges();

  if (state_machine->IsRenderingEnabled())
    rendering_engine->Render();
  else
  {
    neopixel->ShutDown();
    delay(10);
  }

  if (menu_counter == 0xFF || need_to_refresh_menu)
  {
    float current_amps = pwr_controller->AuditPowerStatusAndAct();
    menu->RenderCurrentState(current_amps);
    menu_counter = 0;
    need_to_refresh_menu = false;
  }

  ButtonModule::ButtonAction action = button_module->GetCurrentButtonAction();
  if (action == ButtonModule::ButtonMode || action == ButtonModule::ButtonModeLong 
    || action == ButtonModule::ButtonSelect || action == ButtonModule::ButtonSelectLong)
  {
    StateMachine::ActionType action_type = (StateMachine::ActionType)((int)action - 2);
    state_machine->TransitState(action_type);
    need_to_refresh_menu = true;
  }

  ++menu_counter;
  delayMicroseconds(IdleTimeUs);
}

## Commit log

2021-06-20 led array preview
2021-06-20 turn off led arrays on controller reset
2021-06-20 operative mode implemented (led-wise, no amp meter yet)
2021-06-25 draft +1
    [ambient.sch]
2021-06-25 net list
    [ambient.sch]
2021-06-25 draft +2
    [ambient.kicad_pcb, ambient.sch]
2021-06-26 draft +3
    [ambient.kicad_pcb, ambient.sch]
2021-06-26 pcb draft
    [ambient.kicad_pcb]
2021-06-26 pcb first version
    [ambient.kicad_pcb, ambient.sch]
2021-06-26 bug fixes, first version
    [ambient.kicad_pcb]
2021-06-26 + gerber files
    [ambient-B_Cu.gbr, ambient-B_Mask.gbr, ambient-B_Paste.gbr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]
2021-06-26 + logo
    [ambient.kicad_pcb]
2021-06-27 minor fixes
    [ambient.kicad_pcb]
2021-06-27 fixes for led ic
    [ambient.kicad_pcb, ambient.sch]
2021-06-27 old project deleted
    [kitest.kicad_pcb, kitest.sch]
2021-07-09 RGB WS2812B -> RGBWW SK6812
    [ambient.kicad_pcb, ambient.sch]
2021-08-11 gerber files
    [ambient-B_Cu.gbr, ambient-B_Mask.gbr, ambient-B_Paste.gbr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]
2021-08-11 minor changes
    [ambient.kicad_pcb]
2021-09-18 adjustments to the current configuration
2024-01-31 box foir the new version
    [back.stl, case-bottom-Body001Pad009.stl, case-bottom-BodyPocket002.stl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]
2024-02-06 updated design + pcb
    [ambient.kicad_pcb, ambient.kicad_sch]
2024-04-02 updated size
    [back_v2.stl, case-bottom.FCStd, front_v2.stl]
